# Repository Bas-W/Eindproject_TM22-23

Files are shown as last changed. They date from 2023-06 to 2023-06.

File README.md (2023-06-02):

# eindprojectTM22_23
In dit project maken we een line following robot.
Je vindt in deze repository de bestanden om met een 3D printer de nodige stukken te vervaardigen alsook de code en een pdf waarin uitgelegd wordt hoe de hardware moet worden gemonteerd.

Hoe de server moet worden opgezet wordt niet uitgelegd.

Het project maakt gebruik van MQTT om te communiceren tussen de server en de robot. De robot stuurt data naar de server via MQTT, deze data wordt dan in een influxDB database gezet door een python script. De data kan dan weergegeven worden in een Grafana webpagina. De robot kan ook bediend worden vanuit de webpagina via MQTT berichten.

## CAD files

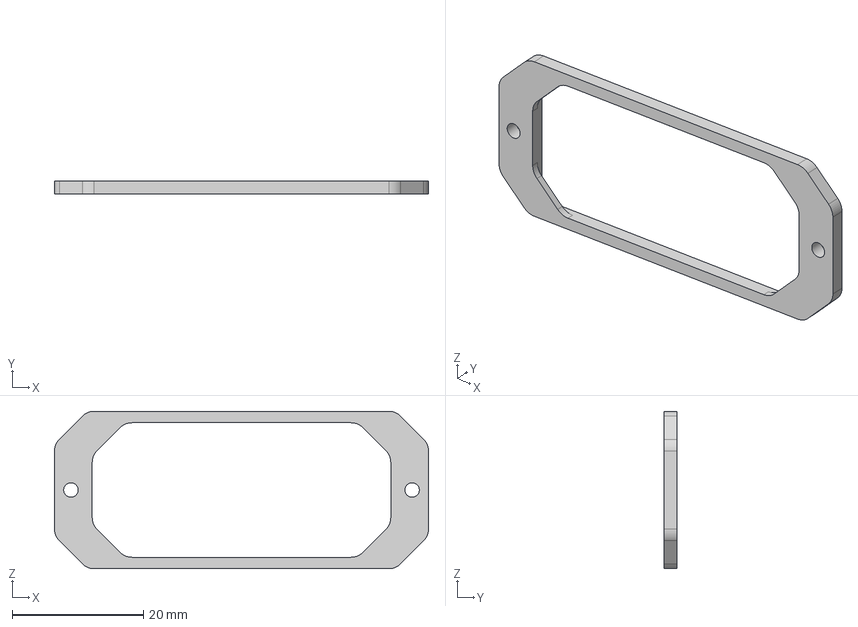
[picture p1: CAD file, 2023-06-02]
CAD/3D_models/Mounting_plate.step
57.0 x 2.00 x 24.0 mm

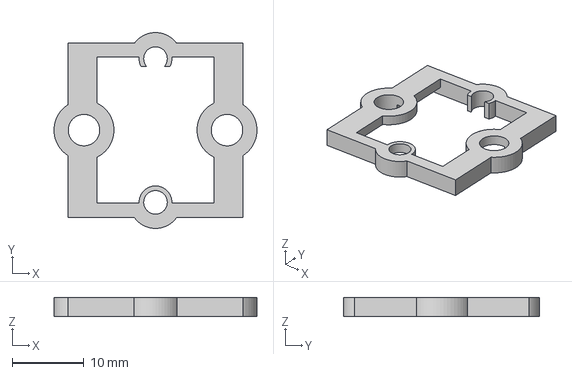
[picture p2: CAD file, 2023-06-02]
CAD/failed_3D_models/IR_sensor_center_mount_adapter.step
28.4 x 27.4 x 2.70 mm

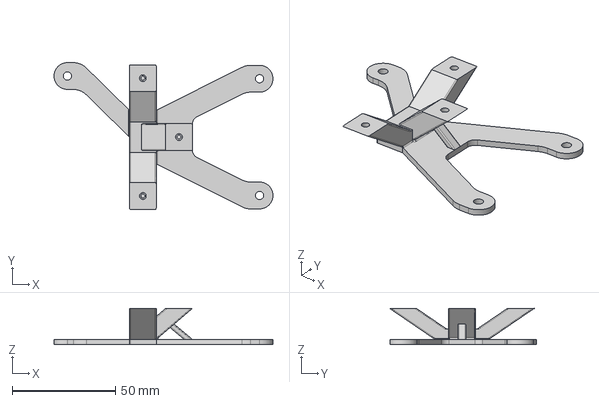
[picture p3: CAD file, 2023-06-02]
CAD/3D_models/Battery_holder_base.step
106.0 x 71.1 x 17.5 mm

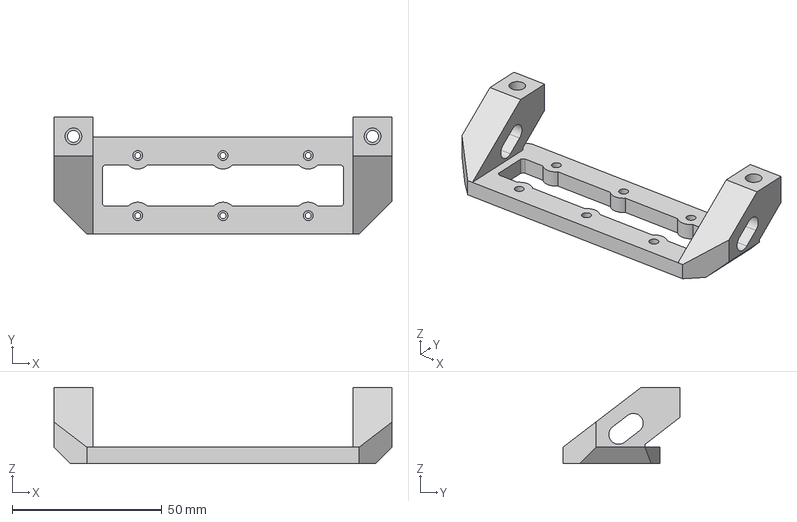
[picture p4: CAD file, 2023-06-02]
CAD/failed_3D_models/IR_sensor_attachment.step
113.0 x 39.2 x 25.5 mm

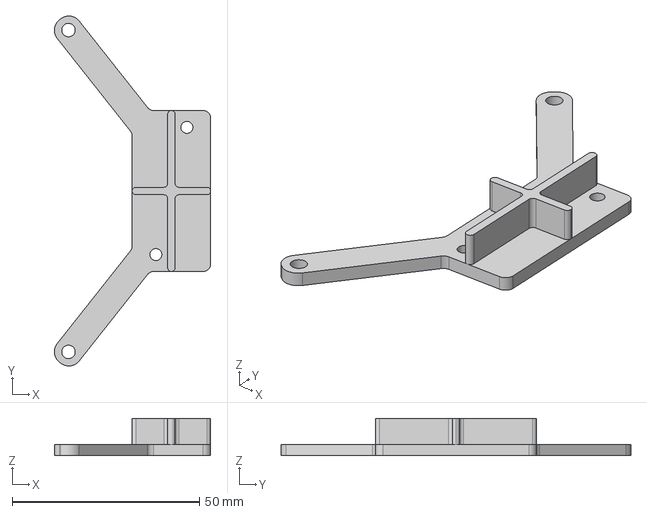
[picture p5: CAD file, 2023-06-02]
CAD/3D_models/Buck_converter_mount.step
41.8 x 93.5 x 10.0 mm

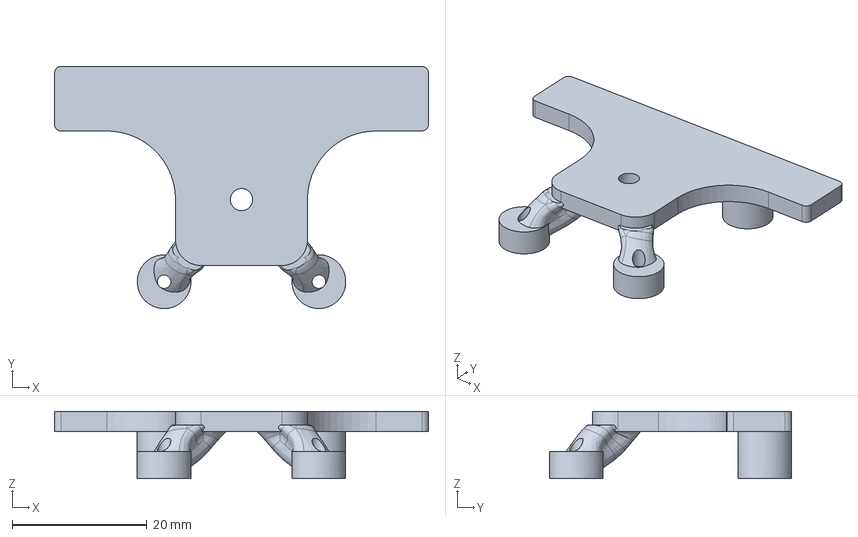
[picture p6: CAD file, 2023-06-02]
CAD/3D_models/Idle_wheel_attachment.step
55.6 x 36.0 x 10.0 mm

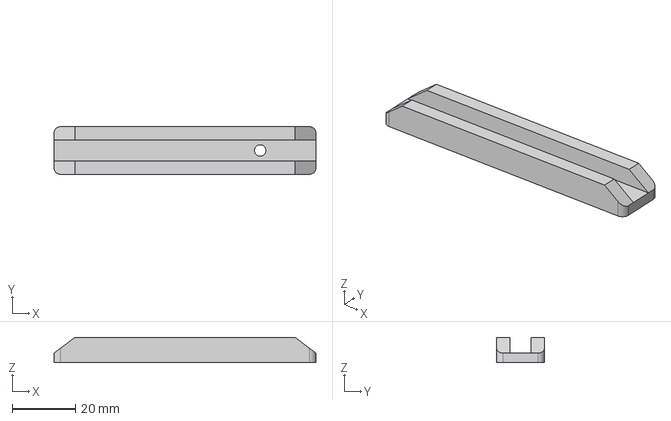
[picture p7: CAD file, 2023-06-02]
CAD/3D_models/Fastener.step
82.6 x 15.0 x 8.00 mm

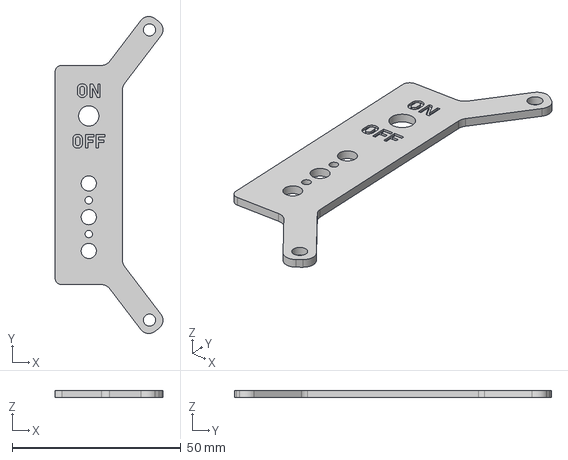
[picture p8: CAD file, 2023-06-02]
CAD/3D_models/LED_and_switch_top.step
32.0 x 93.9 x 2.00 mm

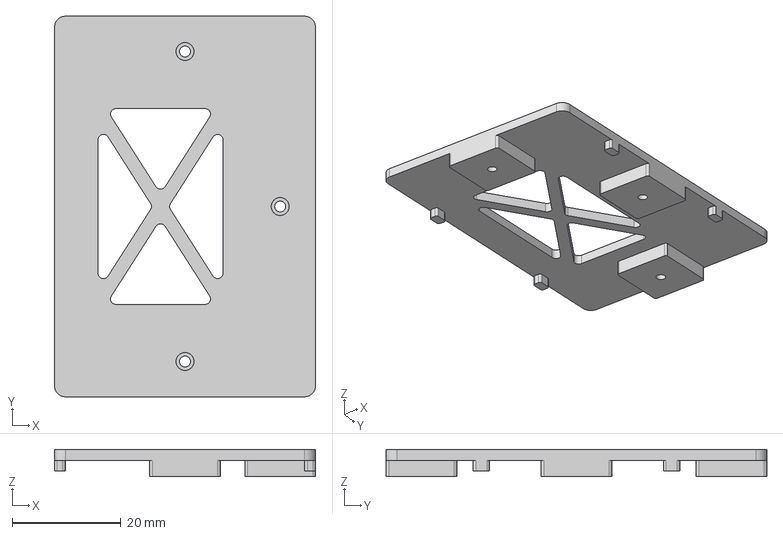
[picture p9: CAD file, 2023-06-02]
CAD/3D_models/Battery_holder_top.step
48.0 x 70.0 x 5.00 mm

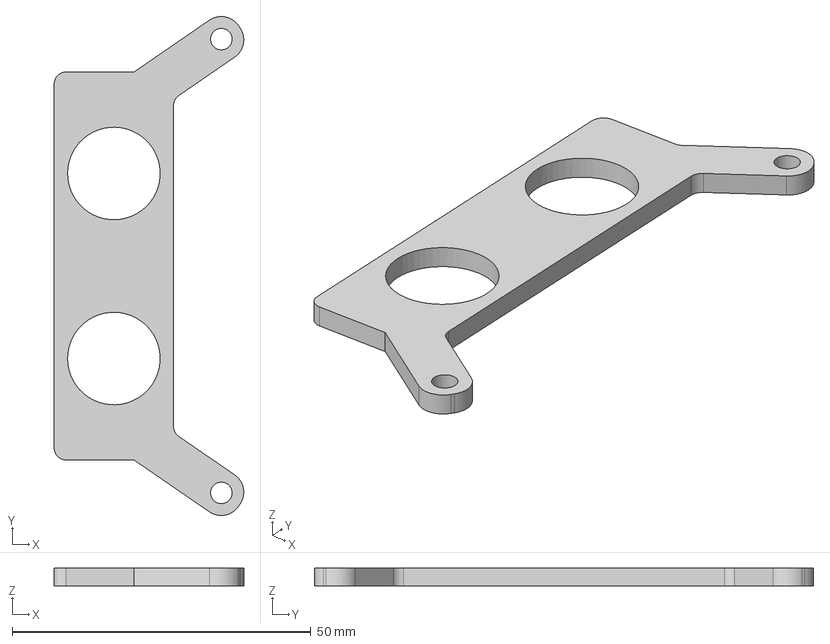
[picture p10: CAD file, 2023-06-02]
CAD/3D_models/Buttons_mount.step
31.8 x 83.6 x 3.00 mm

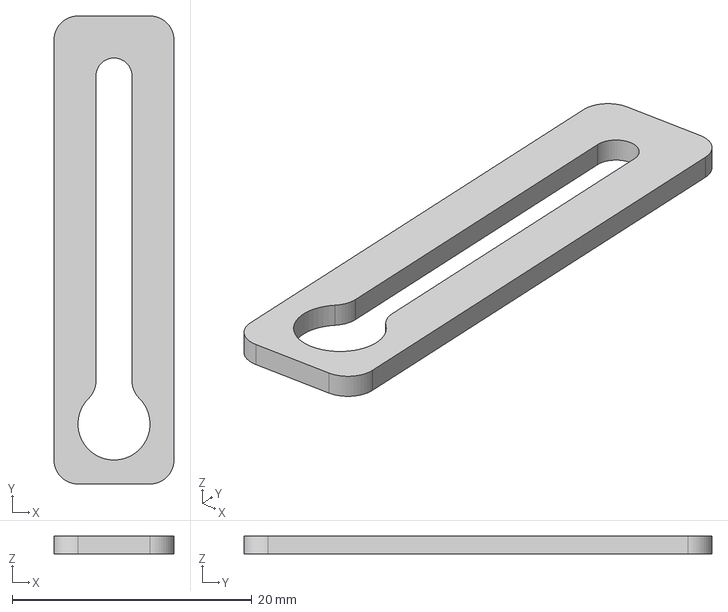
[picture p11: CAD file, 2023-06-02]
CAD/3D_models/LED_and_switch_bottom.step
10.0 x 39.0 x 1.50 mm

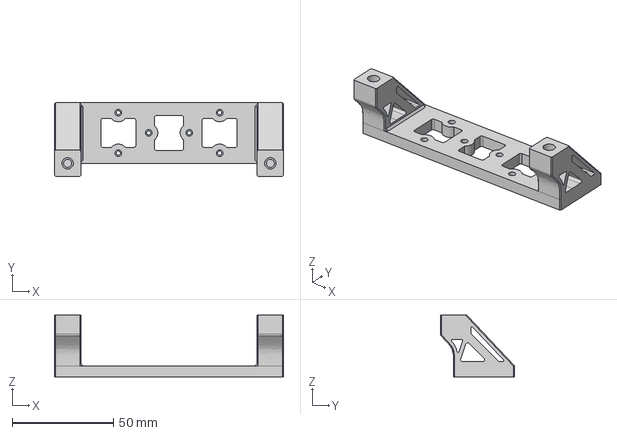
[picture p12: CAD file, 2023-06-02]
CAD/3D_models/IR_sensor_attachment.step
113.0 x 36.5 x 30.5 mm

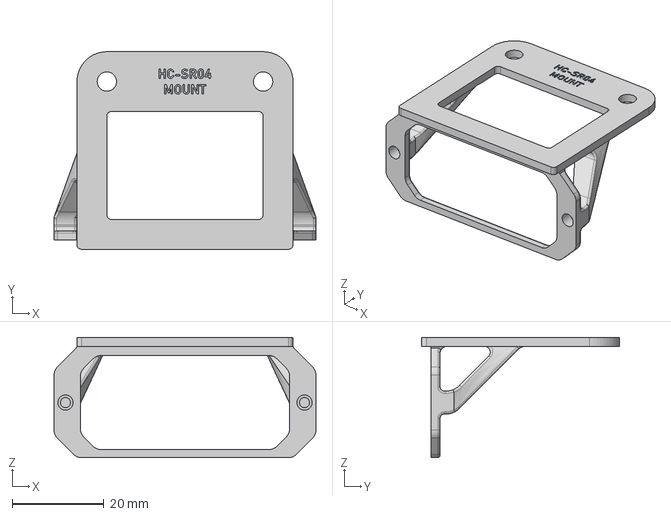
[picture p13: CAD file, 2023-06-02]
CAD/3D_models/Mounting_bracket.step
57.0 x 43.0 x 26.2 mm

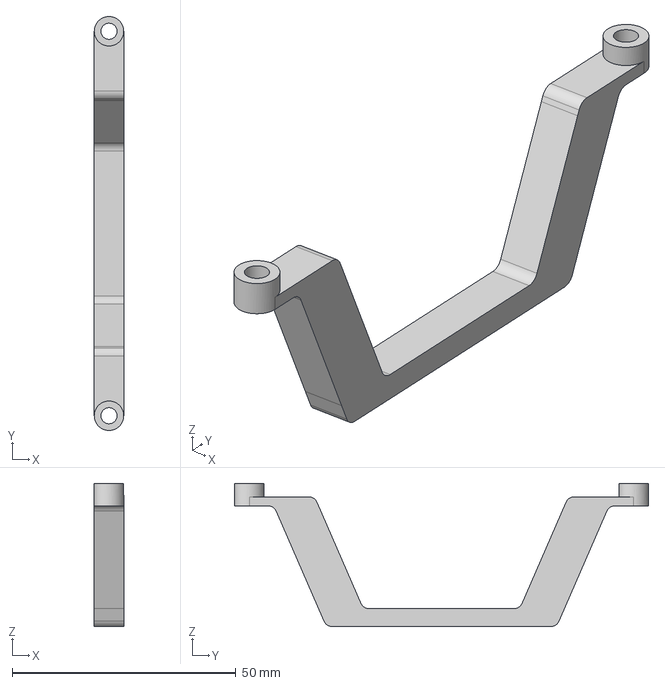
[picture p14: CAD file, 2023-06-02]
CAD/3D_models/PCB_bracket.step
6.60 x 92.6 x 32.0 mm

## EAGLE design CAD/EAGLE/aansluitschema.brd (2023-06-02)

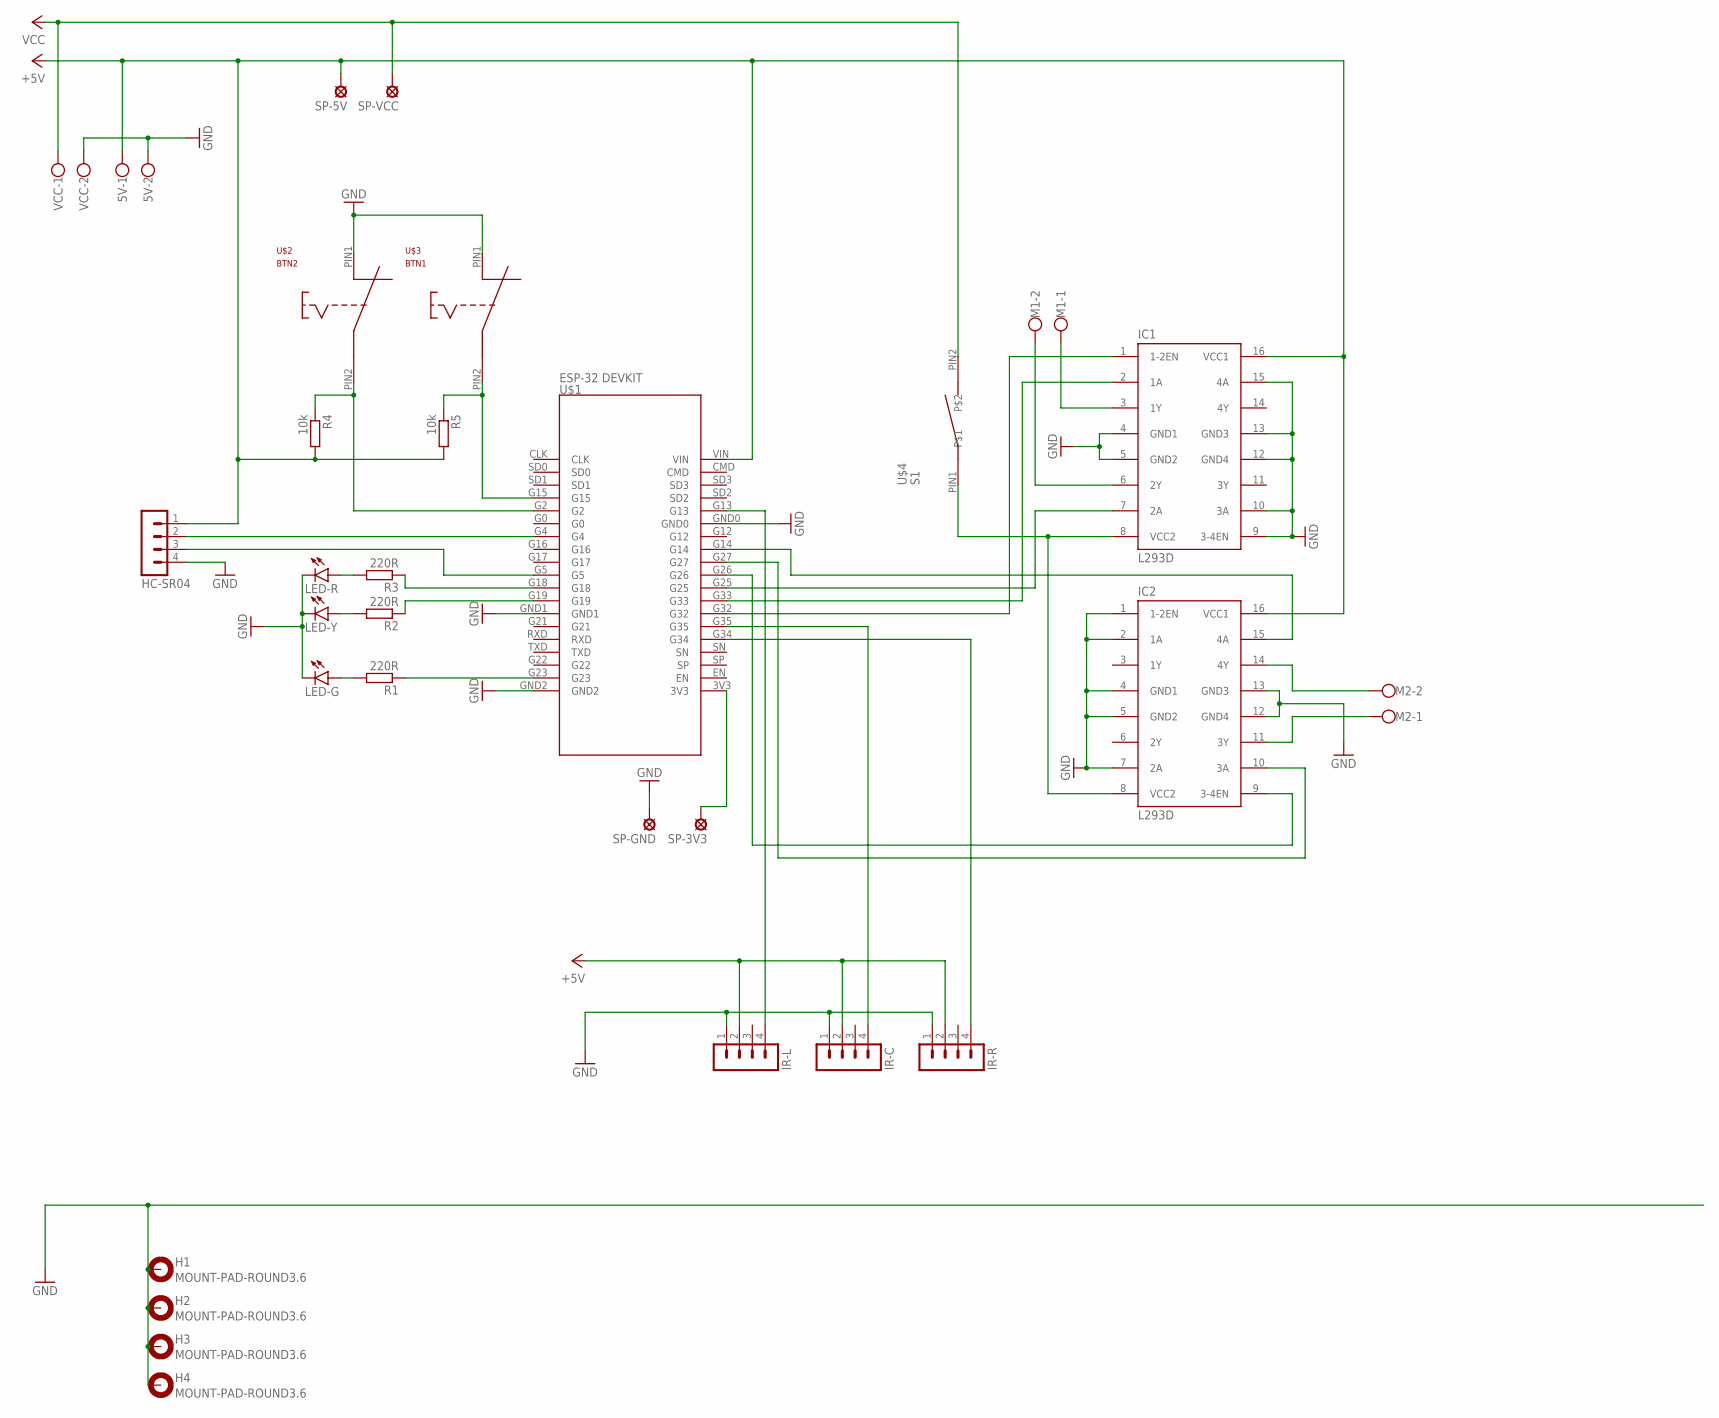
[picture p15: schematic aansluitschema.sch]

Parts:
5V: W237-102
H1, H2, H3, H4: MOUNT-PAD-ROUND3.6; 3,6-PAD
HC-SR04: MA04-1
IC1, IC2: L293D; DIL16
IR-C: MA04-1
IR-L: MA04-1
IR-R: MA04-1
LED-G: LED5MM
LED-R: LED5MM
LED-Y: LED5MM
M1, M2: W237-102
R1, R2, R3: 220R; 0207/10
R4, R5: 10k; 0207/10
SP-3V3, SP-5V: LSP10
SP-GND: LSP10
SP-VCC: LSP10
U$1: ESP-32 DEVKIT; ESP-32_DEVKIT
U$2: BTN2; PUSHBUTTON
U$3: BTN1; PUSHBUTTON
U$4: S1; SWITCH
VCC: W237-102

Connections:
+5V: 5V.1, HC-SR04.1, IC1.16 (VCC1), IC2.16 (VCC1), IR-C.2, IR-L.2, IR-R.2, R4.2, R5.2, SP-5V.MP, U$1.VIN
GND: 5V.2, H1.B3,6, H2.B3,6, H3.B3,6, H4.B3,6, HC-SR04.4, IC1.4 (GND1), IC1.5 (GND2), IC1.9 (3-4EN), IC1.10 (3A), IC1.12 (GND4), IC1.13 (GND3), IC1.15 (4A), IC2.1 (1-2EN), IC2.2 (1A), IC2.4 (GND1), IC2.5 (GND2), IC2.7 (2A), IC2.12 (GND4), IC2.13 (GND3), IR-C.1, IR-L.1, IR-R.1, LED-G.K (C), LED-R.K (C), LED-Y.K (C), SP-GND.MP, U$1.GND0, U$1.GND1, U$1.GND2, U$2.PIN1, U$3.PIN1, VCC.2
unnamed: IC1.8 (VCC2), IC2.8 (VCC2), U$4.PIN1
unnamed: LED-G.A, R1.2
unnamed: LED-Y.A, R2.2
unnamed: LED-R.A, R3.2
unnamed: R2.1, U$1.G19
unnamed: R3.1, U$1.G18
unnamed: R1.1, U$1.G23
unnamed: IR-R.4, U$1.G34
unnamed: IR-C.4, U$1.G35
unnamed: IR-L.4, U$1.G13
unnamed: HC-SR04.3, U$1.G5
unnamed: HC-SR04.2, U$1.G4
unnamed: R4.1, U$1.G2, U$2.PIN2
unnamed: R5.1, U$1.G15, U$3.PIN2
unnamed: IC1.3 (1Y), M1.1
unnamed: IC1.6 (2Y), M1.2
unnamed: IC2.11 (3Y), M2.1
unnamed: IC2.14 (4Y), M2.2
unnamed: IC1.1 (1-2EN), U$1.G32
unnamed: IC1.2 (1A), U$1.G33
unnamed: IC1.7 (2A), U$1.G25
unnamed: IC2.9 (3-4EN), U$1.G26
unnamed: IC2.10 (3A), U$1.G27
unnamed: IC2.15 (4A), U$1.G14
unnamed: SP-3V3.MP, U$1.3V3
VCC: SP-VCC.MP, U$4.PIN2, VCC.1

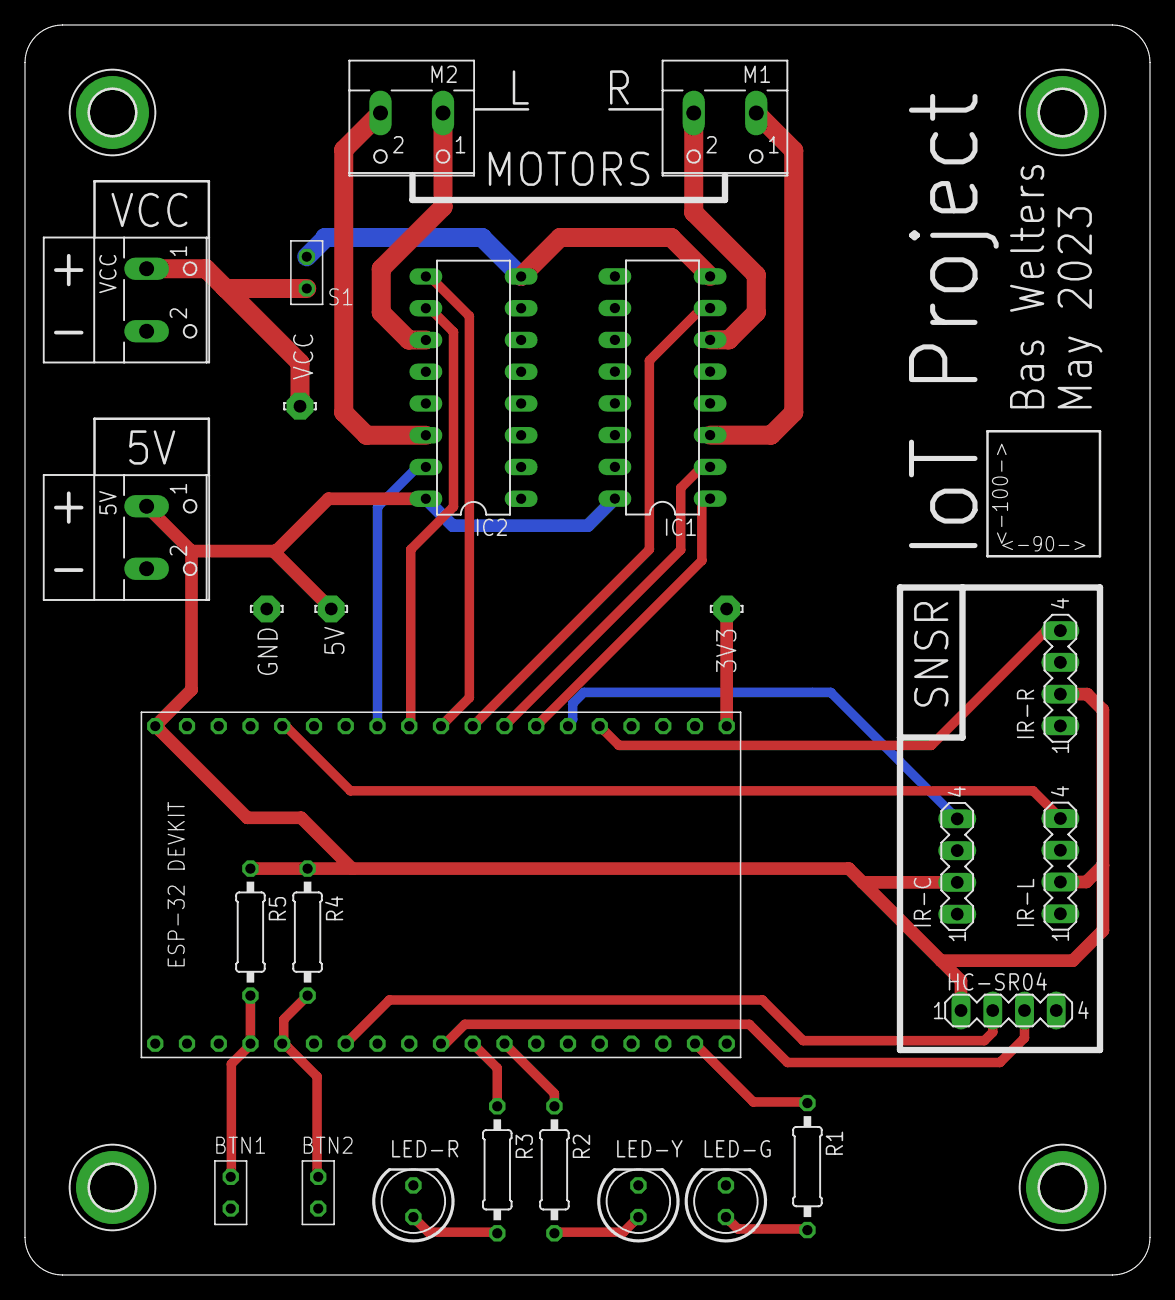
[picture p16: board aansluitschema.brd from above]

Board: 2 copper layers, 90.0 x 100.0 mm, 30 parts (0 on the bottom side), 28 nets.

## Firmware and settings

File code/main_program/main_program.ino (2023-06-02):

TaskHandle_t DriveTask;
TaskHandle_t MQTTTask;
TaskHandle_t distSensTask;

#include <WiFi.h>
#include <PubSubClient.h>

// Options
int maxSpeed = 250; //max motor speed 0-255
int speedOffset = 100;
int line = 0; //does the sensor return 0 or 1 when it sees the line
int transmitDelay = 1000; // Set transmit interval in ms
int sonarDelay = 100; // Set distance ping interval in ms
int minimumDistance = 5; // Set minimum distance to obstacle in cm

// Configuration for wifi and mqtt
const char* ssid = "...";
const char* password = "...";
const char* mqttServer = "...";
const int mqttPort = 1883;
const char* mqttUser = "...";
const char* mqttPassword = "...";
const char* clientID = "...";  // MQTT client ID
const char* listenTopic = "iot_project/lineFLWR";
const char* drivingStatusTopic = "iot_project/status/driving";
const char* batteryTopic = "iot_project/status/battery";
const char* testTopic = "iot_project/status/test";
const char* stateTopic = "iot_project/status/state";

char* drivingStatus = "S"; // Initialize the driving status to "stopped"

int pingPin = 5; // Trigger Pin of Ultrasonic Sensor
int echoPin = 4; // Echo Pin of Ultrasonic Sensor

int button0Pin = 15;
int button1Pin = 2;

int button0State = 0;
int button1State = 0;

// Set transmit interval
int lastTransmitMillis;

// Global variable for obstacle distance
int sonarDistance = 0;
int obstacle = 0;

int IRRightPin = 34;
int IRLeftPin = 13;
int IRCenterPin = 35;

// Define pins for status LED's
int ledOkay = 18;
int ledObstacle = 19;
int ledLostLine = 23;

// Used to handle stopping and starting again
int lastStateIsStop = 0;
int lastStopMillis = 0;
int stopDelay = 5000;
int motorStopOverride = 0;
int stopped = 0;
int shouldContinue = 1;
int manualStop = 0;

// Used for detecting whether the robot has lost track of the line
int lastSeenLineMillis;
int lastSeenLineMaxDelay = 1500;
int lostState = 0;

int IRRightState, IRLeftState, IRCenterState = 0;

//Motor Right
int enA = 32;
int in1 = 33;
int in2 = 25;
//Motor Left
int enB = 26;
int in3 = 27;
int in4 = 14 ;


WiFiClient espClient;
PubSubClient client(espClient);

void setup() {
  Serial.begin(115200);
  WiFi.begin(ssid, password);

  while (WiFi.status() != WL_CONNECTED) {
    Serial.print("Connecting to WiFi network: ");
    Serial.println(ssid);
  }
  Serial.println("Connected to the WiFi network");

  //connect to broker
  client.setServer(mqttServer, mqttPort);

  //set a callback function for when data is received from broker
  client.setCallback(callback);

  // connect to broker
  while (!client.connected()) {
    Serial.println("Connecting to MQTT...");
    if (client.connect(clientID, mqttUser, mqttPassword)) {
      Serial.println("connected");
    } else {
      Serial.print("failed with state ");
      Serial.print(client.state());
      delay(2000);
    }
  }
  // subscribe to topic
  client.subscribe(listenTopic);

  // Set pinMode for sensors
  pinMode(IRRightPin, INPUT);
  pinMode(IRLeftPin, INPUT);
  pinMode(IRCenterPin, INPUT);
  // Set pinMode for buttons en distance sensor
  pinMode(button0Pin, INPUT);
  pinMode(button1Pin, INPUT);
  pinMode(pingPin, OUTPUT);
  pinMode(echoPin, INPUT);

  // Set pinMode for LED's
  pinMode (ledOkay, OUTPUT);
  pinMode (ledObstacle, OUTPUT);
  pinMode (ledLostLine, OUTPUT);

  // Set mode for motor control pins
  pinMode(enA, OUTPUT);
  pinMode(in1, OUTPUT);
  pinMode(in2, OUTPUT);

  pinMode(enB, OUTPUT);
  pinMode(in3, OUTPUT);
  pinMode(in4, OUTPUT);

  // Turn off motors
  digitalWrite(in1, LOW);
  digitalWrite(in2, LOW);
  digitalWrite(in3, LOW);
  digitalWrite(in4, LOW);

  // Turn off LED's
  digitalWrite(ledOkay, LOW);
  digitalWrite(ledObstacle, LOW);
  digitalWrite(ledLostLine, LOW);

  // Indicate that the program has started
  Serial.println("Started");
  client.publish(testTopic, "Started");

  // Run a test sequence for the LED's
  checkLEDs();


  // TASKS
  // Create tasks for controlling the car and communicating over wifi.
  xTaskCreatePinnedToCore(
    DriveTaskCode,   /* Task function. */
    "DriveTask",     /* name of task. */
    10000,       /* Stack size of task */
    NULL,        /* parameter of the task */
    1,           /* priority of the task */
    &DriveTask,      /* Task handle to keep track of created task */
    0);          /* pin task to core 0 */

  xTaskCreatePinnedToCore(
    MQTTTaskCode,   /* Task function. */
    "MQTTTask",     /* name of task. */
    10000,       /* Stack size of task */
    NULL,        /* parameter of the task */
    1,           /* priority of the task */
    &MQTTTask,      /* Task handle to keep track of created task */
    1);          /* pin task to core 1 */

  // Create task for reading the distance sensor, this task has a higher priority than mqttTask. That means it will get priority. mqttTask will only run when this task is paused.
  xTaskCreatePinnedToCore(
    distSensTaskCode,   /* Task function. */
    "distSensTask",     /* name of task. */
    10000,       /* Stack size of task */
    NULL,        /* parameter of the task */
    2,           /* priority of the task */
    &distSensTask,      /* Task handle to keep track of created task */
    1);          /* pin task to core 1 */

  disableCore0WDT();  //Stop watchdog from interrupting the program
  disableCore1WDT();  //Stop watchdog from interrupting the program
}

// Define code to be executed by the driving task
void DriveTaskCode(void * pvParameters) {
  for (;;) {
    followLine();
  }
}

// Define code to be executed by the mqtt task
void MQTTTaskCode(void * pvParameters) {
  for (;;) {
    client.loop();
    doCheckWiFiAndMQTT();

    Serial.print("sending status...");
    client.publish(drivingStatusTopic, drivingStatus);
    Serial.print(drivingStatus);
    if (lostState) {
      client.publish(stateTopic, "Lost");
      Serial.println("..lost");
    }
    else if (stopped) {
      client.publish(stateTopic, "Stopped");
      Serial.println("..stopped");
    }
    else
    {
      client.publish(stateTopic, "OK");
      Serial.println("..ok");
    }


    vTaskDelay(transmitDelay);
  }
}

void distSensTaskCode(void * pvParameters) {
  for (;;) {

    long duration, inches, cm;

    digitalWrite(pingPin, LOW);
    ets_delay_us(2);
    digitalWrite(pingPin, HIGH);
    ets_delay_us(10);
    digitalWrite(pingPin, LOW);
    duration = pulseIn(echoPin, HIGH);
    cm = microsecondsToCentimeters(duration);
    sonarDistance = cm;
    Serial.print(cm);
    Serial.println(" cm");
    vTaskDelay(sonarDelay);
  }
}

void loop() {
}

long microsecondsToCentimeters(long microseconds) {
  return microseconds / 29 / 2;
}

void followLine() {
  //read IR sensors
  IRRightState = digitalRead(IRRightPin);
  IRCenterState = digitalRead(IRCenterPin);
  IRLeftState = digitalRead(IRLeftPin);
  button0State = digitalRead(button0Pin);
  button1State = digitalRead(button1Pin);

  if (button0State) {
    manualStop = 0;
  }
  if (button1State) {
    manualStop = 1;
  }

  if (sonarDistance < minimumDistance) {
    stopMotors();
    Serial.println("Obstacle");
    drivingStatus = "O";
    digitalWrite(ledOkay, LOW);
    digitalWrite(ledObstacle, HIGH);
    digitalWrite(ledLostLine, LOW);
    obstacle = 1;
    lastSeenLineMillis = millis();
  }
  else if (! manualStop) {
    obstacle = 0;
    digitalWrite(ledObstacle, LOW);

    if ((IRRightState == line) && !(IRLeftState == line) && ((millis() - lastStopMillis) > (stopDelay + 500))) {
      // Turn right
      digitalWrite(ledOkay, HIGH);
      digitalWrite(ledObstacle, LOW);
      digitalWrite(ledLostLine, LOW);
      turnRight(maxSpeed);
      Serial.println("Right");
      drivingStatus = "R";
      lastStateIsStop = 0;

      lastSeenLineMillis = millis();
    }
    else if ((IRLeftState == line) && !(IRRightState == line) && ((millis() - lastStopMillis) > (stopDelay + 500))) {
      // Turn left
      digitalWrite(ledOkay, LOW);
      digitalWrite(ledObstacle, LOW);
      digitalWrite(ledLostLine, LOW);
      turnLeft(maxSpeed);
      Serial.println("Left");
      drivingStatus = "L";
      lastStateIsStop = 0;

      lastSeenLineMillis = millis();
    }
    else if ((IRCenterState == line) && !(IRLeftState == line || IRRightState == line)) {
      // Straight ahead
      digitalWrite(ledOkay, HIGH);
      digitalWrite(ledObstacle, LOW);
      digitalWrite(ledLostLine, LOW);
      goStraight((maxSpeed - speedOffset));
      Serial.println("Forward");
      drivingStatus = "F";
      lastStateIsStop = 0;

      lastSeenLineMillis = millis();
    }
  }
  else {
    stopMotors();
  }
  if ((IRCenterState == line) && (IRLeftState == line) && (IRRightState == line) && (! manualStop)) {
    // Stop
    if ((!lastStateIsStop) && ((millis() - lastStopMillis) > (stopDelay + 1000))) {
      shouldContinue = 0;
      stopMotors();
      Serial.println("Stop");
      drivingStatus = "S";
      stopped = 1;
      lastStateIsStop = 1;
      lastStopMillis = millis();
    }
    else if (((millis() - lastStopMillis) > stopDelay) || button0State) {
      shouldContinue = 1;
    }

    lastSeenLineMillis = millis();
    if (shouldContinue) {
      goStraight((maxSpeed - speedOffset));
      stopped = 0;
    }
  }

  if ((millis() - lastSeenLineMillis) > lastSeenLineMaxDelay) {
    stopMotors();
    digitalWrite(ledLostLine, HIGH);
    digitalWrite(ledOkay, LOW);
    lostState = 1;
  }
  else {
    digitalWrite(ledLostLine, LOW);
    digitalWrite(ledOkay, HIGH);
    lostState = 0;
  }
}

void turnLeft(int motorSpeed) {
  //Set motor speed 0-255
  analogWrite(enA, motorSpeed);
  analogWrite(enB, motorSpeed);

  //Reverse motor left
  digitalWrite(in1, LOW);
  digitalWrite(in2, HIGH);

  //Forward motor right
  digitalWrite(in3, LOW);
  digitalWrite(in4, HIGH);
}

void turnRight(int motorSpeed) {
  //Set motor speed 0-255
  analogWrite(enA, motorSpeed);
  analogWrite(enB, motorSpeed);

  //Forward motor left
  digitalWrite(in1, HIGH);
  digitalWrite(in2, LOW);

  //Reverse motor right
  digitalWrite(in3, HIGH);
  digitalWrite(in4, LOW);
}

void goStraight(int motorSpeed) {
  //Set motor speed 0-255
  analogWrite(enA, motorSpeed);
  analogWrite(enB, motorSpeed);

  //Forward motor left
  digitalWrite(in1, HIGH);
  digitalWrite(in2, LOW);

  //Forward motor right
  digitalWrite(in3, LOW);
  digitalWrite(in4, HIGH);
}

void goBack (int motorSpeed) {
  //Set motor speed 0-255
  analogWrite(enA, motorSpeed);
  analogWrite(enB, motorSpeed);

  //Reverse motor left
  digitalWrite(in1, LOW);
  digitalWrite(in2, HIGH);

  //Reverse motor right
  digitalWrite(in3, HIGH);
  digitalWrite(in4, LOW);
}

void stopMotors() {
  //Set motor speed 0-255
  analogWrite(enA, 50);
  analogWrite(enB, 50);

  //Stop motor left
  digitalWrite(in1, LOW);
  digitalWrite(in2, LOW);

  //Stop motor right
  digitalWrite(in3, LOW);
  digitalWrite(in4, LOW);
}

void doCheckWiFiAndMQTT() {
  //check wifi connection and reconnect if necessary
  if (WiFi.status() != WL_CONNECTED) {
    Serial.print("\n");
    Serial.println("WiFi disconnected!");
    while (WiFi.status() != WL_CONNECTED) {
      Serial.print("Connecting to WiFi network: ");
      Serial.println(ssid);
    }
    Serial.println("Connected to the WiFi network");
  }

  // check MQTT connection and reconnect to broker if necessary
  if (!client.connected() && (WiFi.status() == WL_CONNECTED)) {
    Serial.print("\n");
    Serial.println("MQTT disconnected!");
    while (!client.connected()) {
      Serial.println("Connecting to MQTT...");
      if (client.connect(clientID, mqttUser, mqttPassword)) {
        Serial.println("connected");
      } else {
        Serial.print("failed with state ");
        Serial.println(client.state());
        delay(2000);
      }
    }
    // subscribe to topic
    client.subscribe(listenTopic);
  }
}

void checkLEDs() {
  digitalWrite(ledOkay, HIGH);
  delay(500);
  digitalWrite(ledObstacle, HIGH);
  delay(500);
  digitalWrite(ledLostLine, HIGH);
  delay(2000);
  digitalWrite(ledOkay, LOW);
  digitalWrite(ledObstacle, LOW);
  digitalWrite(ledLostLine, LOW);
}

void callback(char* topic, byte* payload, unsigned int length) {

  Serial.print("Message arrived with topic: ");
  Serial.println(topic);

  // Detect wether a start or stop signal has been received. 1 for start, 0 for stop.
  if (payload[0] == '1') {
    shouldContinue = 1;
    manualStop = 0;
  }
  else if (payload[0] == '0') {
    manualStop = 1;
  }

  Serial.println("Message: ");
  for (int i = 0; i < length; i++) {
    Serial.print((char)payload[i]);
  }
  Serial.println("");
}
